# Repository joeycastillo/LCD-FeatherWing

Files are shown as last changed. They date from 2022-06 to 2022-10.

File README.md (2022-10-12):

# FeatherWing with Liquid Crystal Display

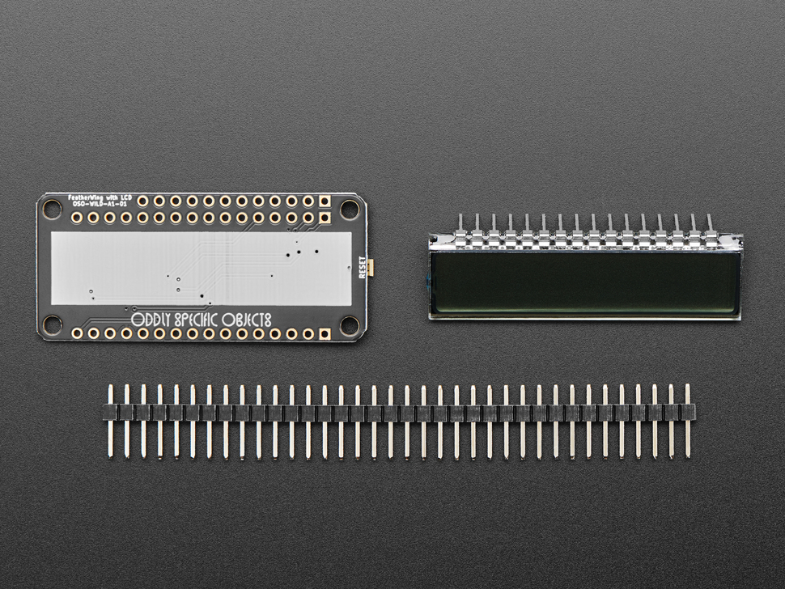
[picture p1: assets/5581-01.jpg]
<a href="https://www.adafruit.com/product/5581"><br/>

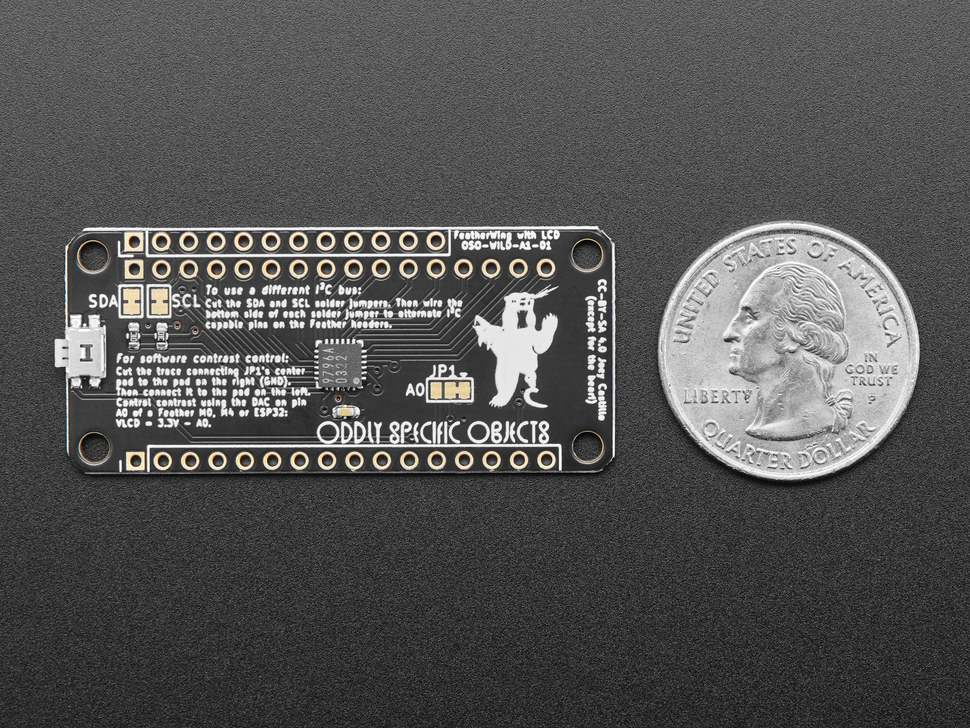
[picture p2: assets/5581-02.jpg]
<a href="http://www.adafruit.com/products/5581"><br/>
Click here to purchase one from the Adafruit shop</a>

This repository contains design files for the LCD FeatherWing — available at both [Adafruit](http://www.adafruit.com/products/5581) and the [Oddly Specific Objects shop](https://shop.oddlyspecificobjects.com) — and the LCD FeatherWing test jig.

PLEASE NOTE: The FeatherWing schematics and PCB designs, as well as the test jig and even the LCD data sheet and artwork are all open source hardware covered by the CC-BY-SA 4.0 license. You should feel absolute freedom to remix and change them, or even make these objects on your own for any commercial or noncommercial purpose.

The only exceptions are the Oddly Specific Objects trade marks, including the Oddly Specific Objects typography and the lazer bear artwork. If you want to make these boards and sell them, feel free to do so, and to credit OSO as inspiration! I just ask that you remove the branding from the boards if you're going to sell them on your own.

Please don't steal the bear.

## OSO-WILD-A1

This folder contains KiCad schematics and board designs for revision 01 of the LCD FeatherWing. The BOM couldn't be more simple:

* 1x [BU9796AMUV-E2](https://www.digikey.com/en/products/detail/rohm-semiconductor/BU9796AMUV-E2/5253944) 48-segment LCD controller
* 1x [732-7057-6-ND](https://www.digikey.com/en/products/detail/würth-elektronik/434351045816/5209090) tactile switch
* 2x 10K resistors (0805)
* 1x 100nF capacitor (0805)

You will also need some very basic [0.1 inch breakaway header](https://www.adafruit.com/product/392), and one of the custom LCDs described in the next section:

## OSO-WILD-A2

This folder contains designs for the liquid crystal display glass, as sent to my LCD manufacturer. If you were to design your own 48-segment LCD, the dimensions, pinout and pin spacing in the datasheet document would ensure compatibility with the FeatherWing. In addition, these files should give you an idea of the kinds of information an LCD fabricator would need to realize your design.

## OSO-WILD-A3

This folder contains a KiCad board design for revision 00 of the LCD FeatherWing tester. There is no schematic or BOM for this, but it just uses some [Feather headers](https://www.adafruit.com/product/2886) at the top, some [pogo pins](https://www.adafruit.com/product/394) in the middle and one of the aforementioned LCDs at the bottom, plus some [M2.5 standoffs](https://www.adafruit.com/product/3299).

[The test procedure](https://twitter.com/josecastillo/status/1528408183030566913) is pretty straightforward: load a script onto the Feather — preferably one that exercises each segment individually — and then place the wing in the test jig. Press the reset button on the wing (which confirms that the reset button is functional) and then watch the LCD on the tester. If the expected output appears, the board passes!

If segments appear incorrectly, check for bridged pins or bad joints on the one QFN part. If nothing displays at all, check on that as well as the two resistors by the reset button.

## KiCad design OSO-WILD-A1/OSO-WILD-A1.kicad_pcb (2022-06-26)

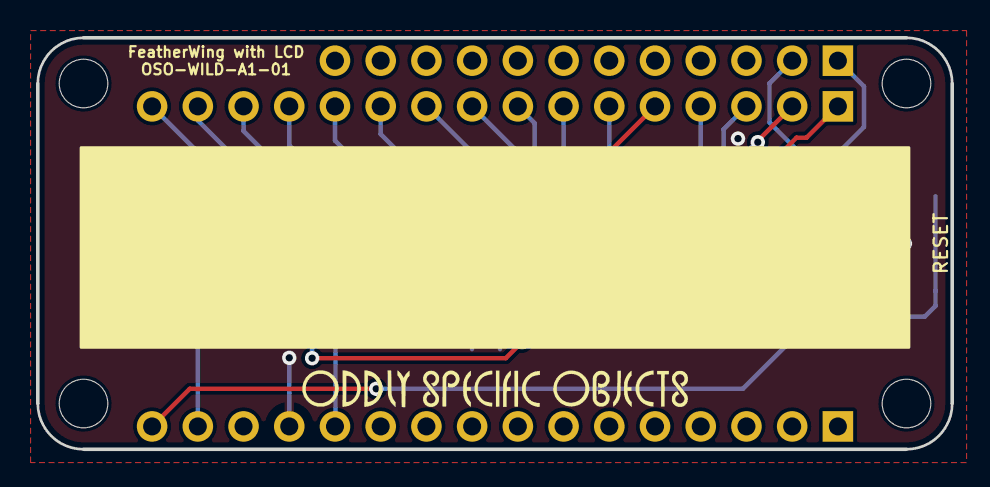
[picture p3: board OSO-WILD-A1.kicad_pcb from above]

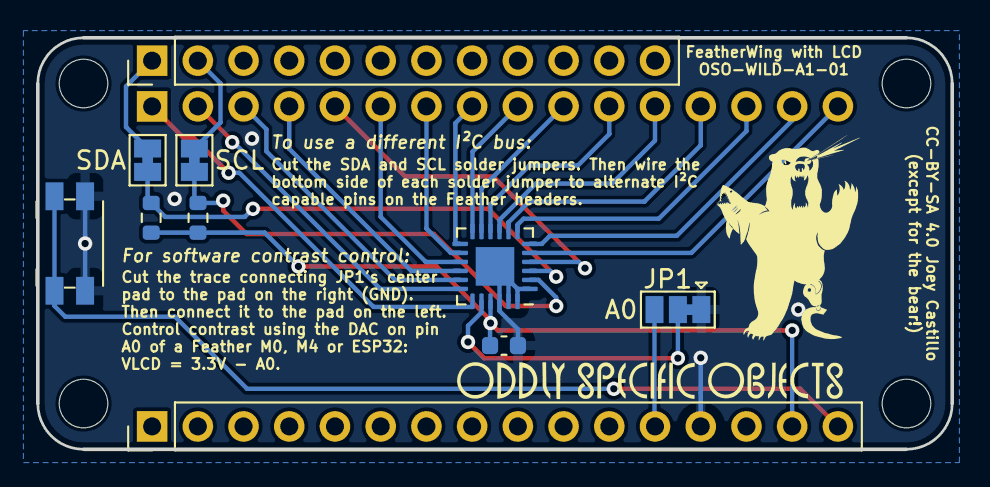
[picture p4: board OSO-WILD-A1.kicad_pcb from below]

Board: 2 copper layers, 50.8 x 22.9 mm, 11 parts (10 on the bottom side), 25 nets.

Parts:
C1: 0.1uF; C_0603_1608Metric
J1: feather long; PinHeader_1x16_P2.54mm_Vertical
J2: feather short; PinHeader_1x12_P2.54mm_Vertical
JP1: Jumper_3_Bridged12; SolderJumper-3_P1.3mm_Bridged12_Pad1.0x1.5mm
JP2, JP3: Jumper_2_Bridged; SolderJumper-2_P1.3mm_Bridged_Pad1.0x1.5mm
LCD1: Conn_01x16_Female; PinHeader_1x16_P2.54mm_Vertical
R1, R2: 10K; R_0603_1608Metric
SW1: SW_Push; Panasonic_EVQPUJ_EVQPUA
U1: BU9796AMUV-E2; QFN-24-1EP_4x4mm_P0.5mm_EP2.15x2.15mm

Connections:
+3V3: C1.1, J1.15, R1.1, R2.1, U1.21 (VDD)
/A0: J1.12, JP1.3 (B)
/COM0: LCD1.4, U1.16 (COM0)
/COM1: LCD1.3, U1.17 (COM1)
/COM2: LCD1.2, U1.18 (COM2)
/COM3: LCD1.1, U1.19 (COM3)
/SCL: J2.2, JP3.1 (A)
/SCL_LCD: JP3.2 (B), R2.2, U1.2 (SCL)
/SDA: J2.1, JP2.1 (A)
/SDA_LCD: JP2.2 (B), R1.2, U1.3 (SDA)
/SEG0: LCD1.5, U1.4 (SEG0)
/SEG1: LCD1.16, U1.5 (SEG1)
/SEG2: LCD1.15, U1.6 (SEG2)
/SEG3: LCD1.14, U1.7 (SEG3)
/SEG4: LCD1.13, U1.8 (SEG4)
/SEG5: LCD1.12, U1.9 (SEG5)
/SEG6: LCD1.11, U1.10 (SEG6)
/SEG7: LCD1.10, U1.11 (SEG7)
/SEG8: LCD1.9, U1.12 (SEG8)
/SEG9: LCD1.8, U1.13 (SEG9)
/SEG10: LCD1.7, U1.14 (SEG10)
/SEG11: LCD1.6, U1.15 (SEG11)
/VLCD: JP1.2 (C), U1.20 (VLCD)
/~RST: J1.16, SW1.1
GND: C1.2, J1.13, JP1.1 (A), SW1.2, U1.1 (OSCIN), U1.22 (VSS), U1.23 (TEST1), U1.24 (TEST2), U1.25 (EPAD)

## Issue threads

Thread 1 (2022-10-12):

Add a Qwiic or STEMA connector

pacav69, 2022-10-12:
I think you could add a add an option for a Qwiic or STEMA connector to the board this would add compatibility and flexibility to the Adafruit ecosystem and other boards such as the ESP32  series.
It could be just the pads so that a SMD could be soldered at a later time or be soldered in place as a purchase option.

Here is a link on the connectors
https://www.adafruit.com/product/4208
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

joeycastillo, 2022-10-12:
I think it's a great idea! Alas it might require a fairly extensive redesign; the reset button is occupying the spot on the board nearest to the I2C pins, so it would likely have to move to the opposite side to make room for a STEMMA-QT port there.

I still have a lot of the current boards in stock, but if the time comes that I need to order and manufacture more, I will definitely consider this possibility. Thanks for the suggestion!

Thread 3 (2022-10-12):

Open Source Hardware logo

pacav69, 2022-10-12:
For the next batch of boards you could add the Open Source Hardware logo
found here:
https://kicad.github.io/footprints/Symbol

joeycastillo, 2022-10-12:
Thanks for the suggestion! I have a lot of the current boards still in stock but it’s something I will consider if I do a second revision.

Closed 2022-10-12.

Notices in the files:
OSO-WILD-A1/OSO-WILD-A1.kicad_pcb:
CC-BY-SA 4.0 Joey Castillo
